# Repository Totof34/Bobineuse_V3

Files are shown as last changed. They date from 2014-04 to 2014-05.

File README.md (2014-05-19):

Bobineuse_V3
============

The project describes a stand-alone coil winder

If you would have more information about this project please visit 
www.audiyofan.org

A link to the dedicated post 
http://www.audiyofan.org/forum/viewtopic.php?f=73&t=7176&start=105

PCB & schema are designed with Kicad

the motor part uses a DC motor with a home made supply described below

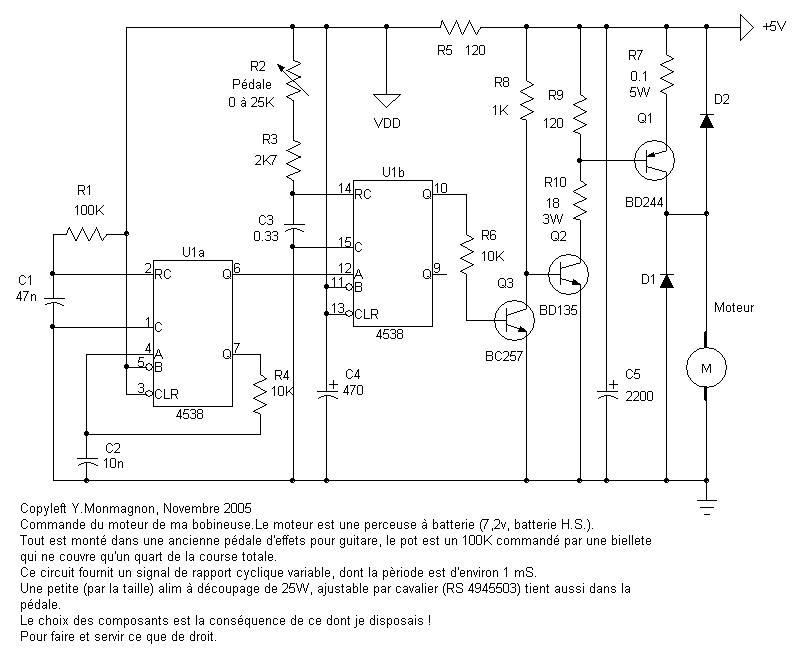
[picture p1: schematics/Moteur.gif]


The prototype of the display and the buttons

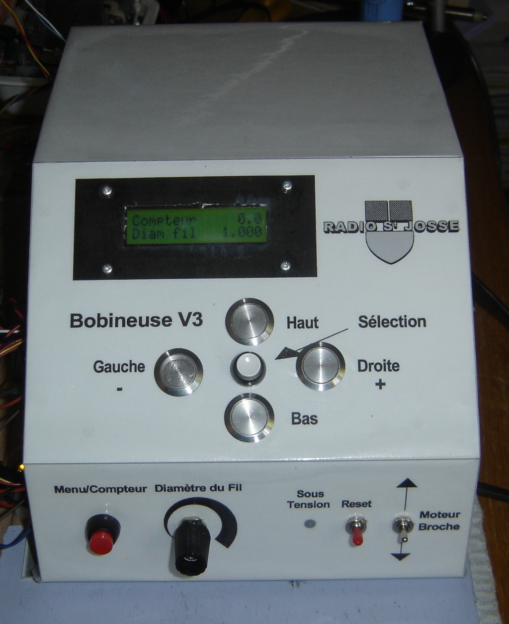
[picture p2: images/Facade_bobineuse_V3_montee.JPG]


The optical fork's disc 

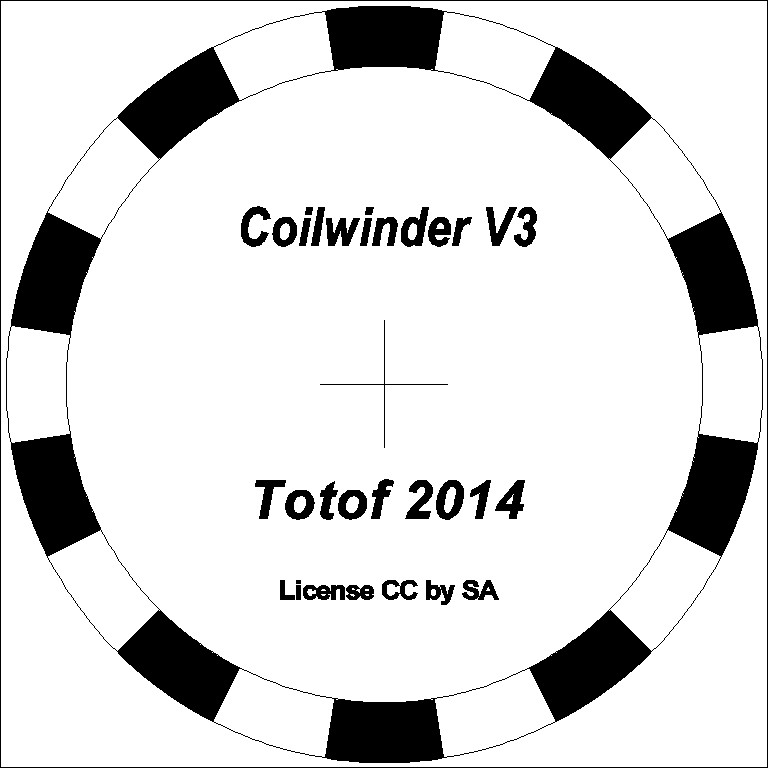
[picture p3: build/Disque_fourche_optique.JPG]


Everything that goes around the Leonardo's board

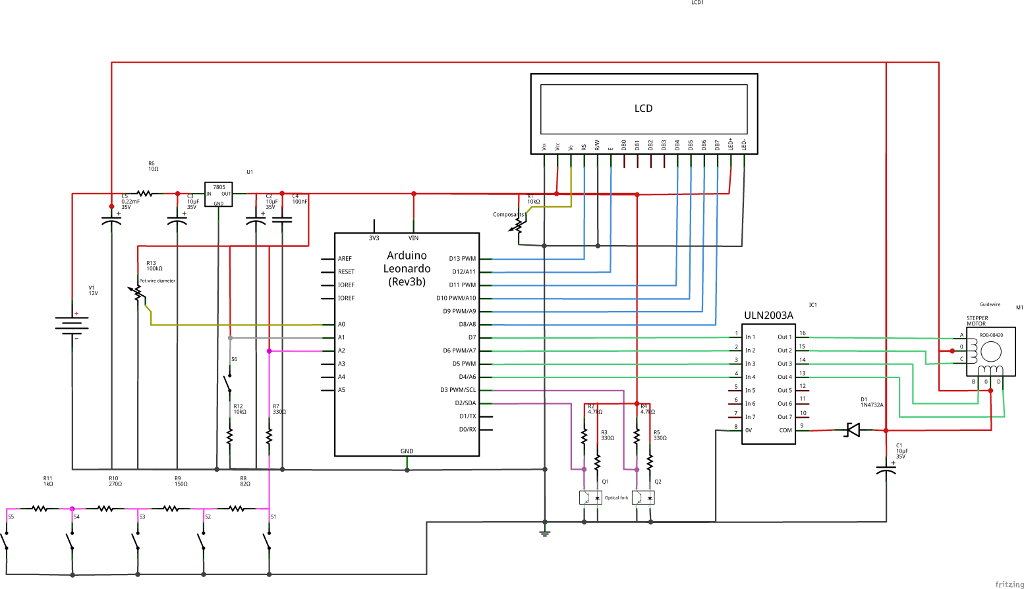
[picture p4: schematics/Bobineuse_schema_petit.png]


Here the function than my program include and which seems to me appropriate

 1° automatic counting and uncounting
 
 2° counting from zero or down from a specified number of turns
 
 3° initial point or initial carcass start recordable and reminder 
 
 4° guide wire enslaved on the up / down counting
 
 5° automatic reversing guide wire depending on the number of turns per layer and change side
 
 6° manual correction of errors in advance of the guide wire, losses step essentially
 
 7° Manual correction of counting errors
 
 8° management parameters by a "management" menu and a second separate part for the counting itself
 
 9° recordings of 10 different configurations to facilitate the winding of several transformers,
    by recording the primary and secondary sections separately and recall stored data in memory
    
10° display menus on 16x2 characters LCD

Of course my Leonardo's board also allows PC control if you wanted to, but I prefer a
standalone machine

See in the arduino folder for the sketch

Detail of the guidewire

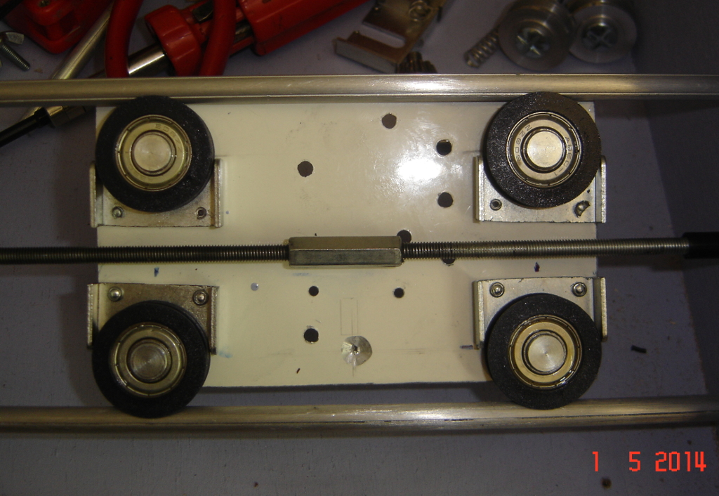
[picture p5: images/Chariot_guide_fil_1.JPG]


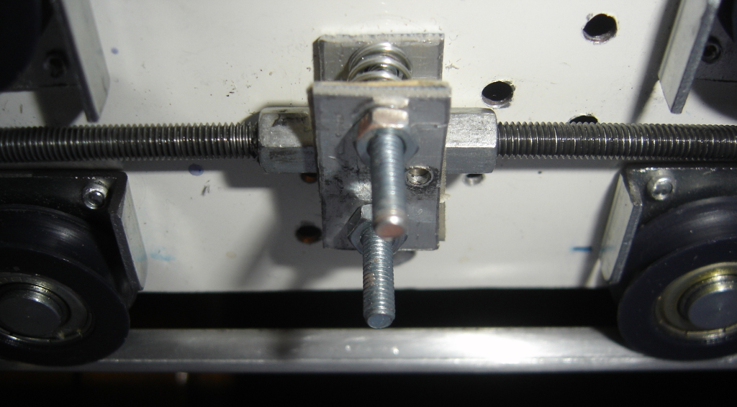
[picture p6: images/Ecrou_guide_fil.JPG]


Implementation of electronic boards in progress

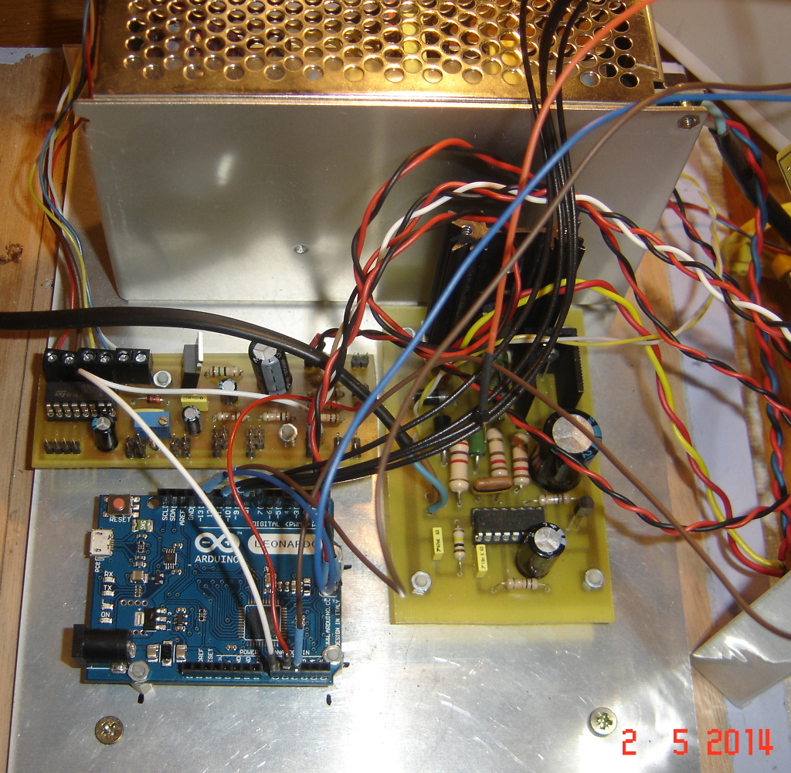
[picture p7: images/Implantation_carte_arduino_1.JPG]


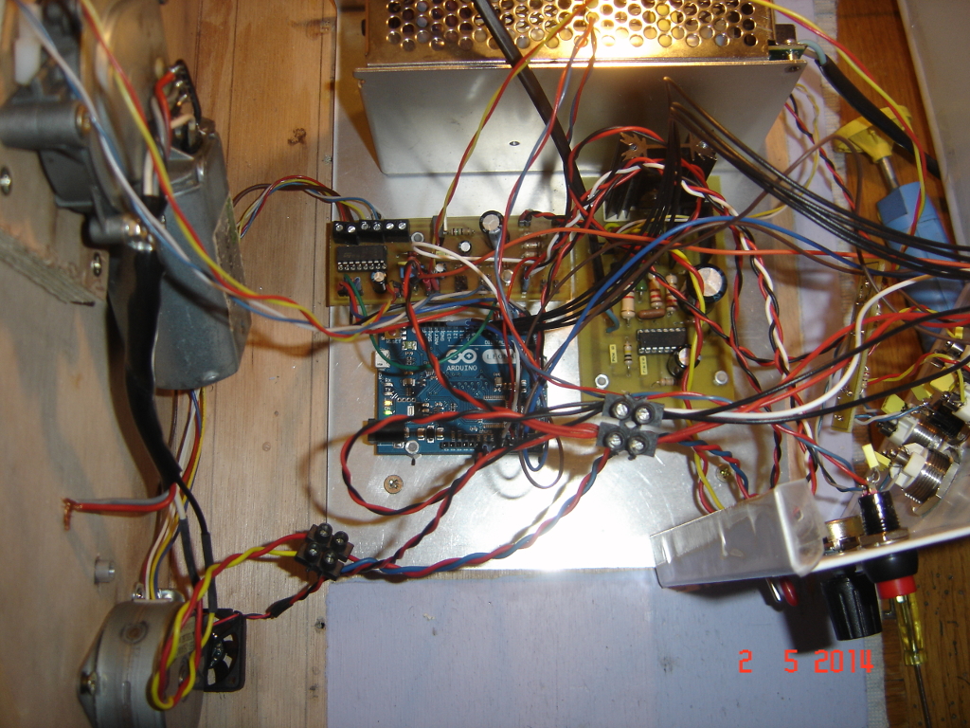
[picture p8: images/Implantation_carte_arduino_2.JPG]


Work in progress

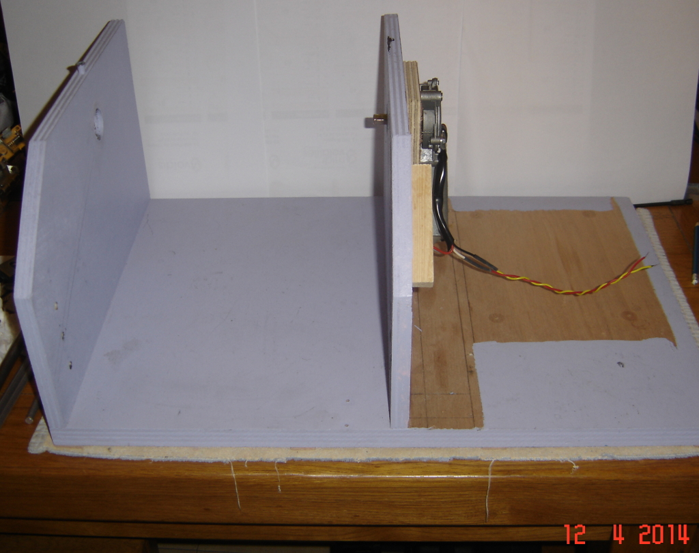
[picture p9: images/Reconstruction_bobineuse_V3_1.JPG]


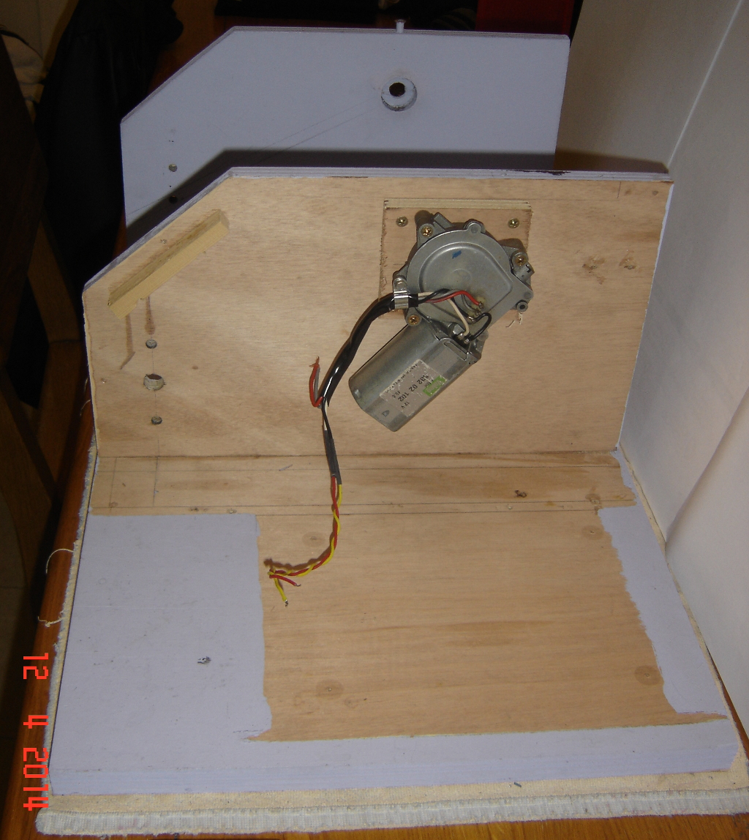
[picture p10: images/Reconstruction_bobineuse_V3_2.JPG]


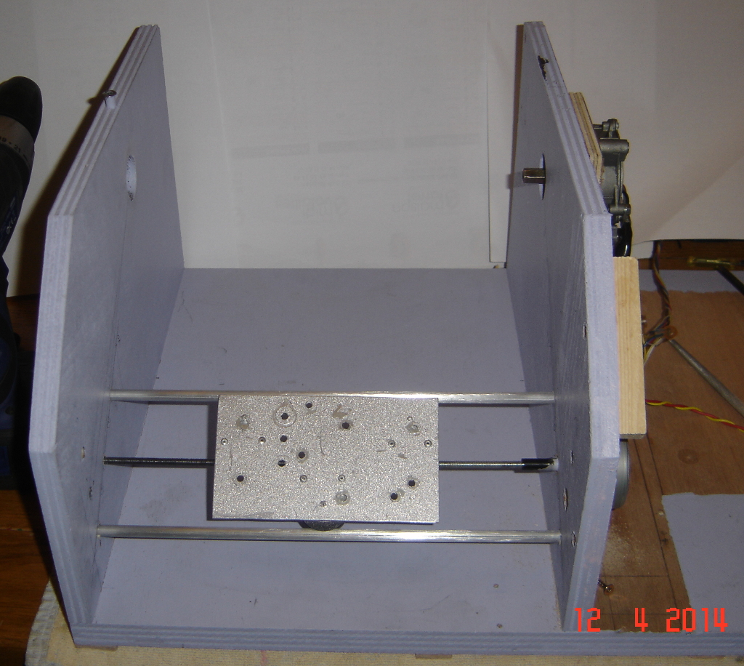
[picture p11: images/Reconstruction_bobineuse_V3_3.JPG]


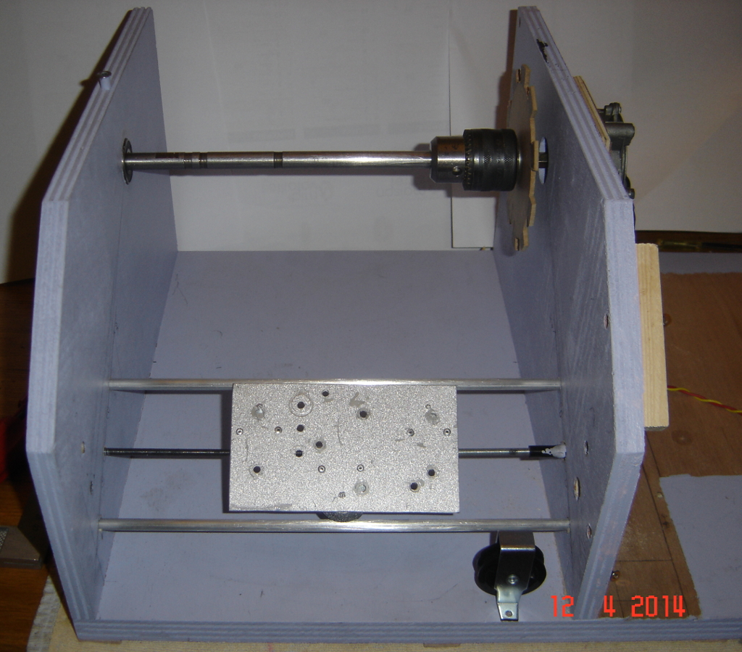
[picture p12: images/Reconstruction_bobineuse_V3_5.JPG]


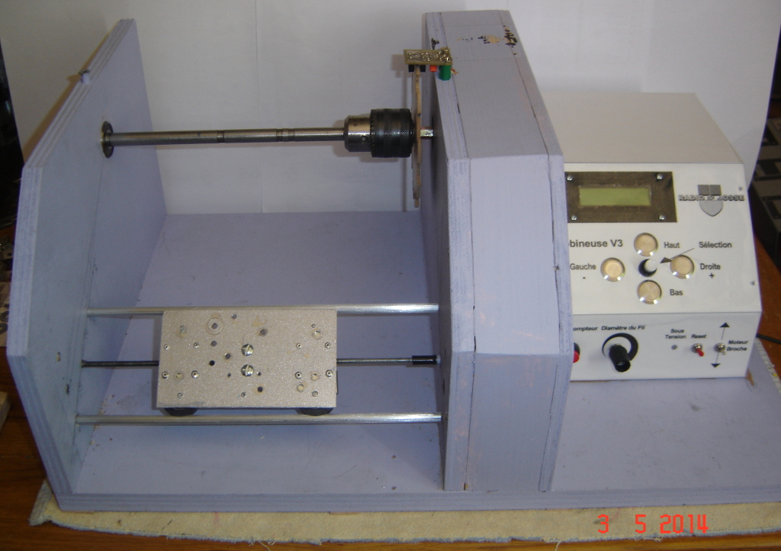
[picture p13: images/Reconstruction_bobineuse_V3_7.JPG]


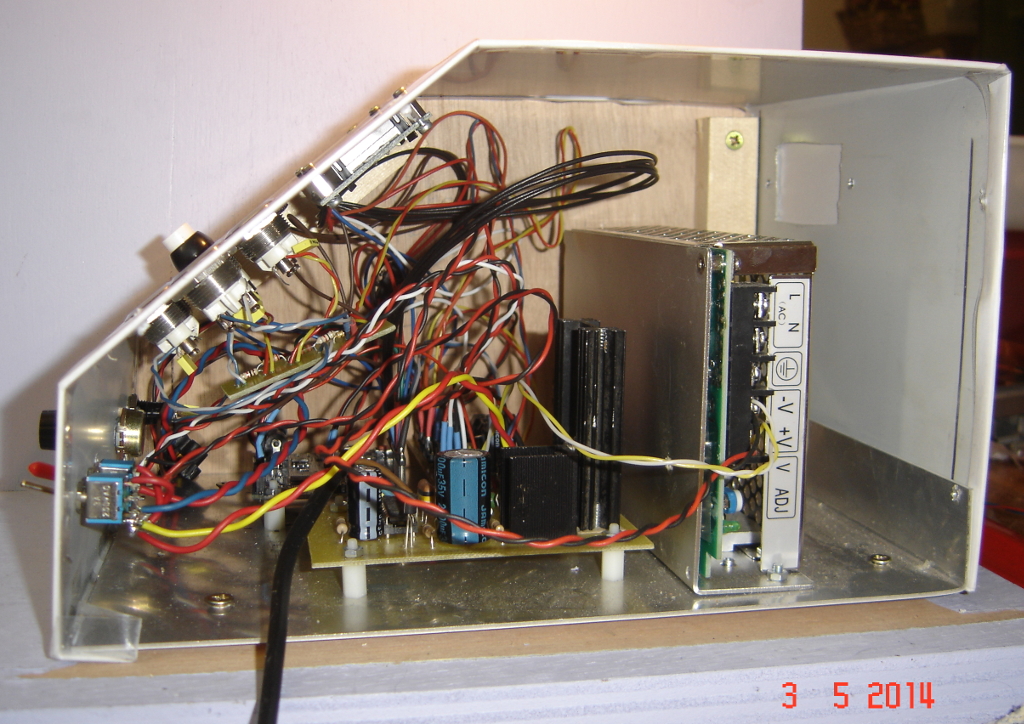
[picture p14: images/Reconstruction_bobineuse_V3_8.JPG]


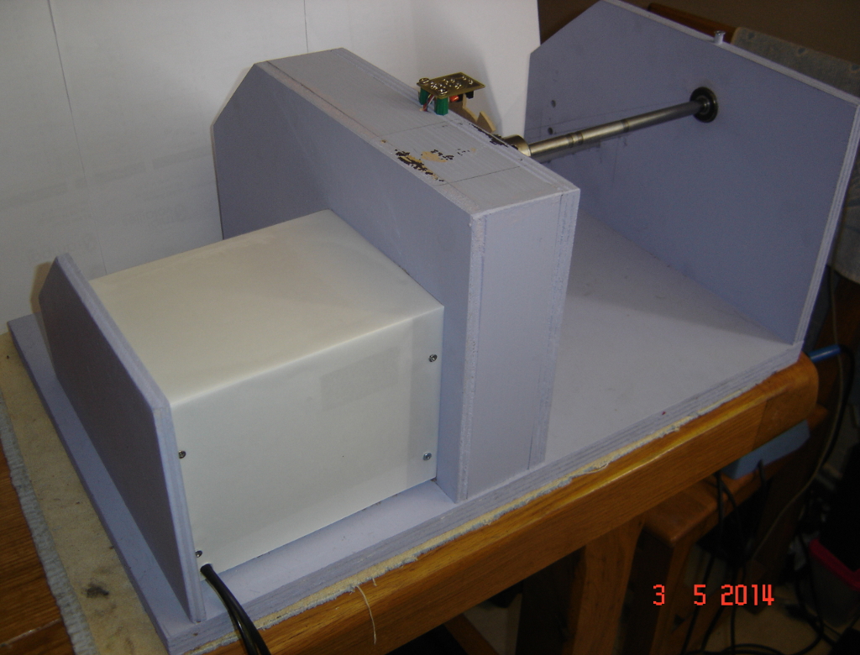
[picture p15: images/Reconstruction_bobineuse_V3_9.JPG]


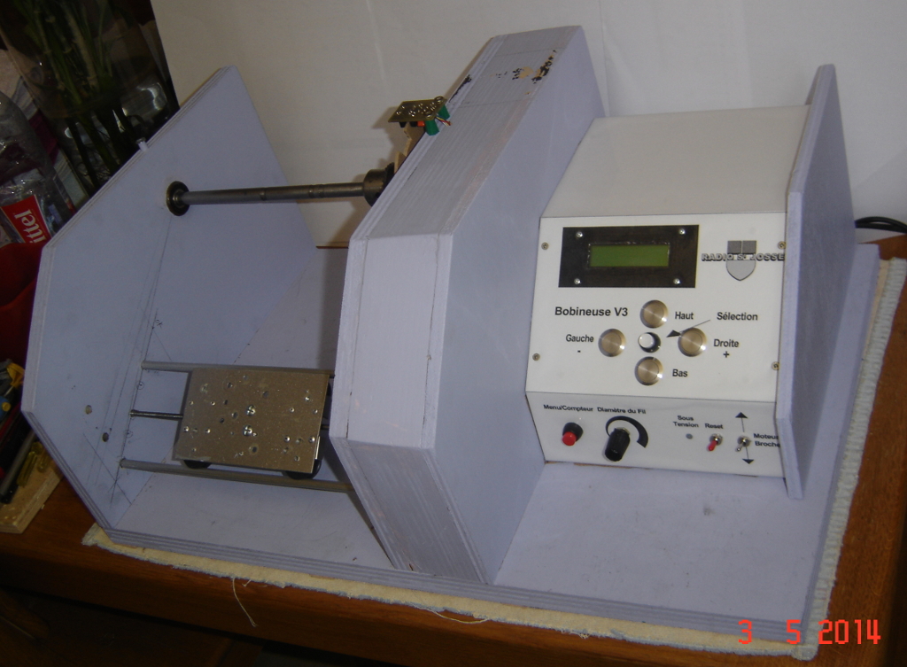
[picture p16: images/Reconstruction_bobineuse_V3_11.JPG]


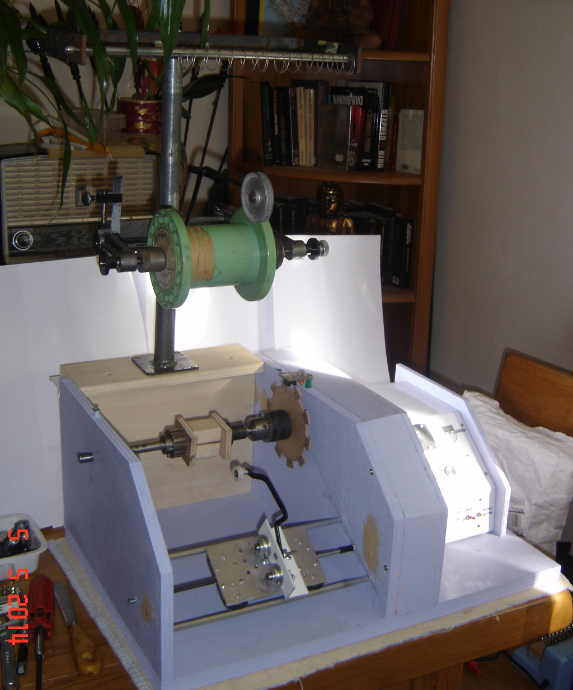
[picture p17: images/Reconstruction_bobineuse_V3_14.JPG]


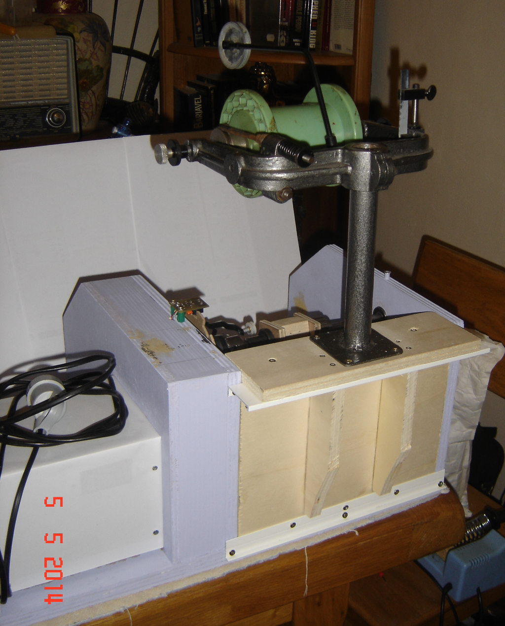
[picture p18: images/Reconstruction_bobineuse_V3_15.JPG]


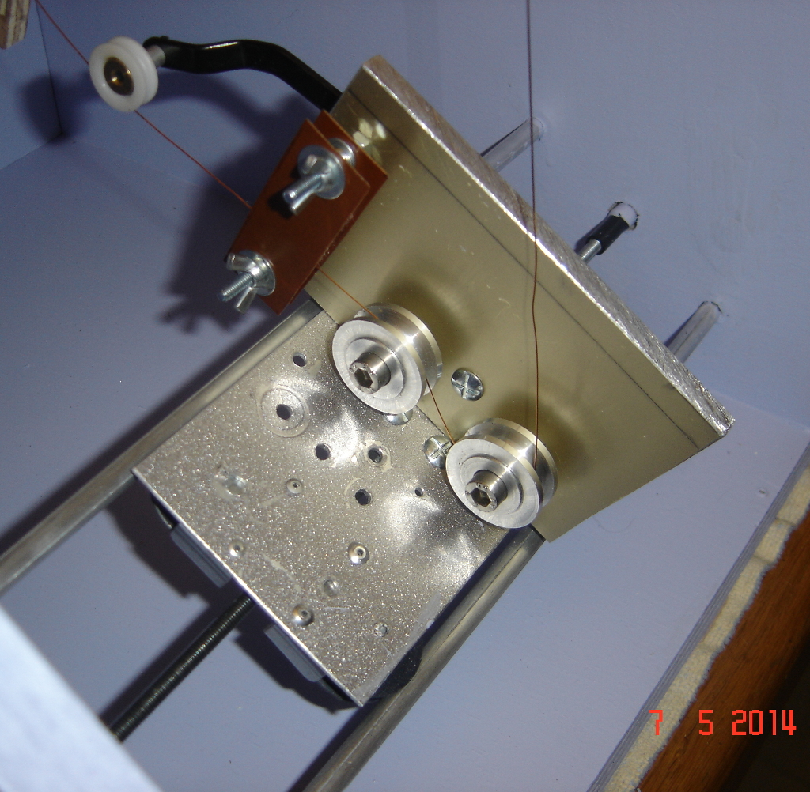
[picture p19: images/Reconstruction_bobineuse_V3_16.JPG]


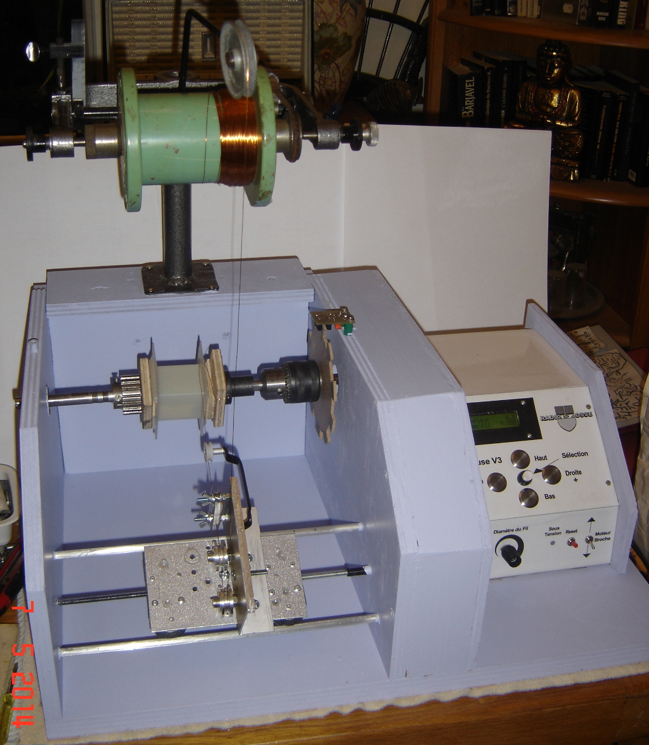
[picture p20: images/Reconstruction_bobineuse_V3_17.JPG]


The coilwinder in function 

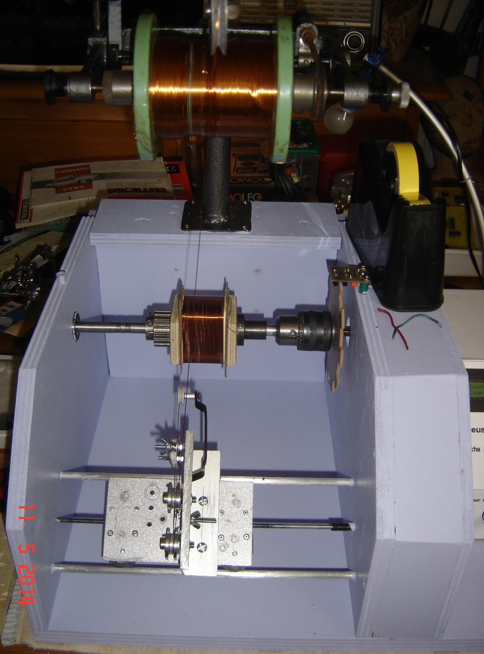
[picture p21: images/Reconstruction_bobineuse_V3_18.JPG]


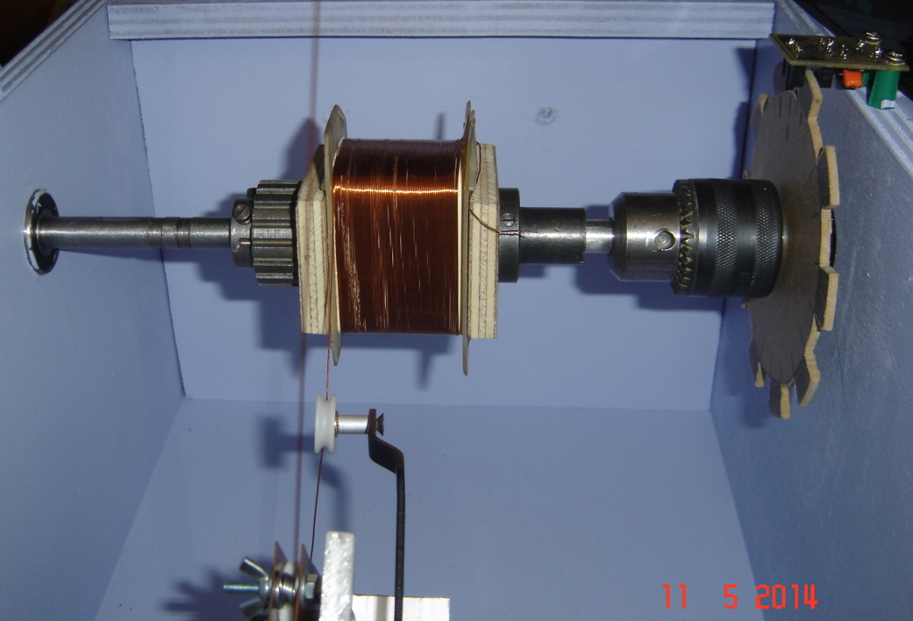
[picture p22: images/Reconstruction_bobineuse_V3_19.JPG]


Addition of a carrier for high copper coil

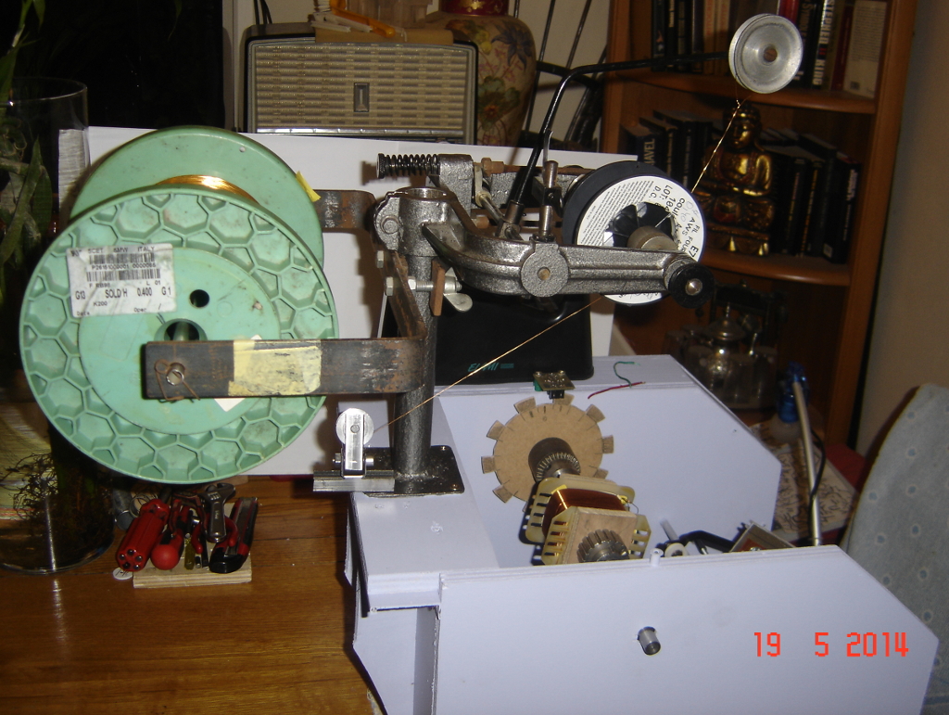
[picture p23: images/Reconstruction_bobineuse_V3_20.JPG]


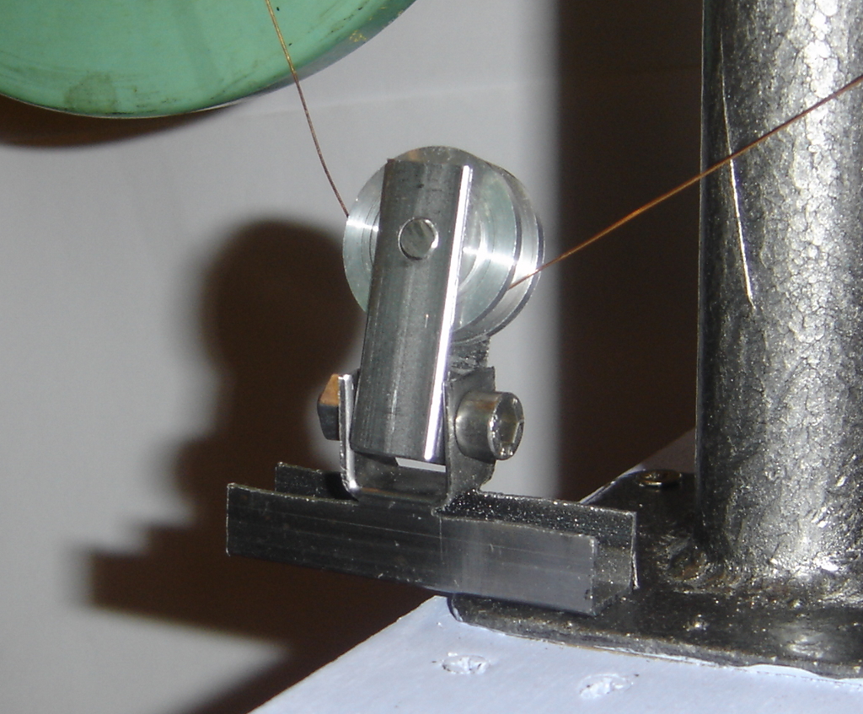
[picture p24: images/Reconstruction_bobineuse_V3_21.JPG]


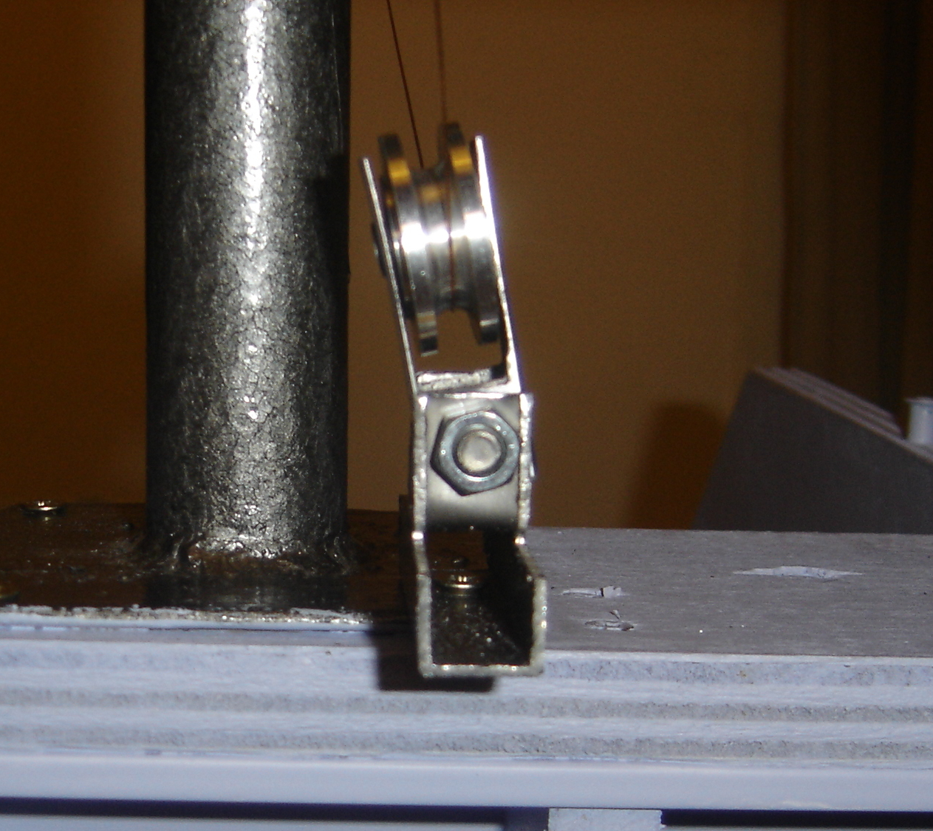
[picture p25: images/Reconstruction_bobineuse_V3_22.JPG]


All comments are welcome

Totof

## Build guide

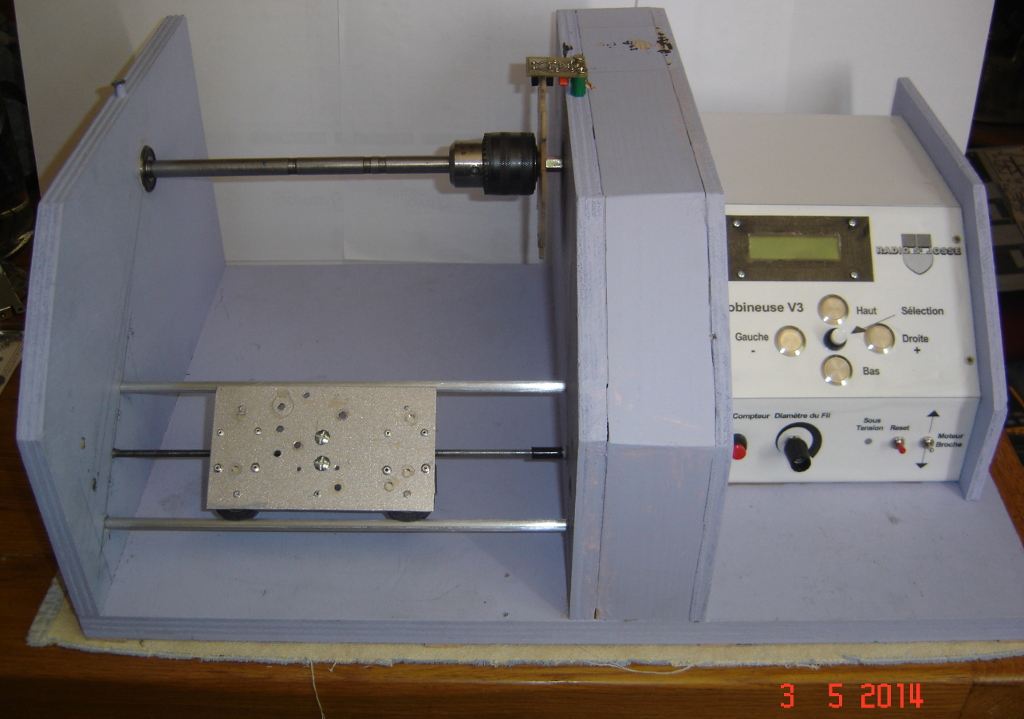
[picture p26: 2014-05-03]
images/Reconstruction_bobineuse_V3_10.JPG

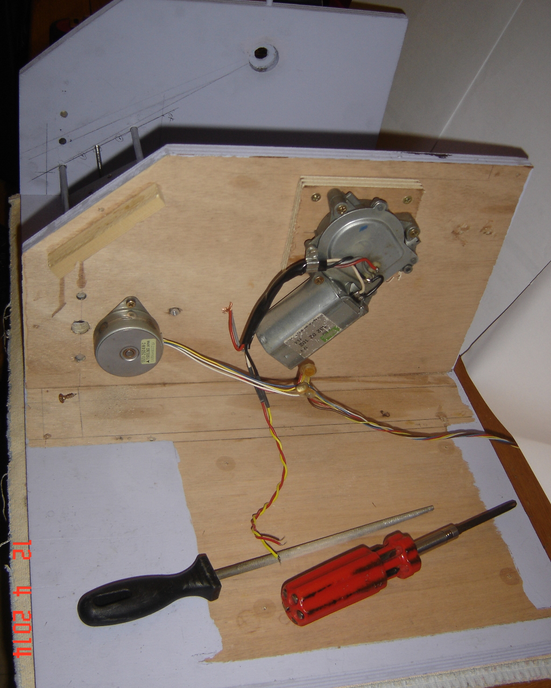
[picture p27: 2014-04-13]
images/Reconstruction_bobineuse_V3_4.JPG

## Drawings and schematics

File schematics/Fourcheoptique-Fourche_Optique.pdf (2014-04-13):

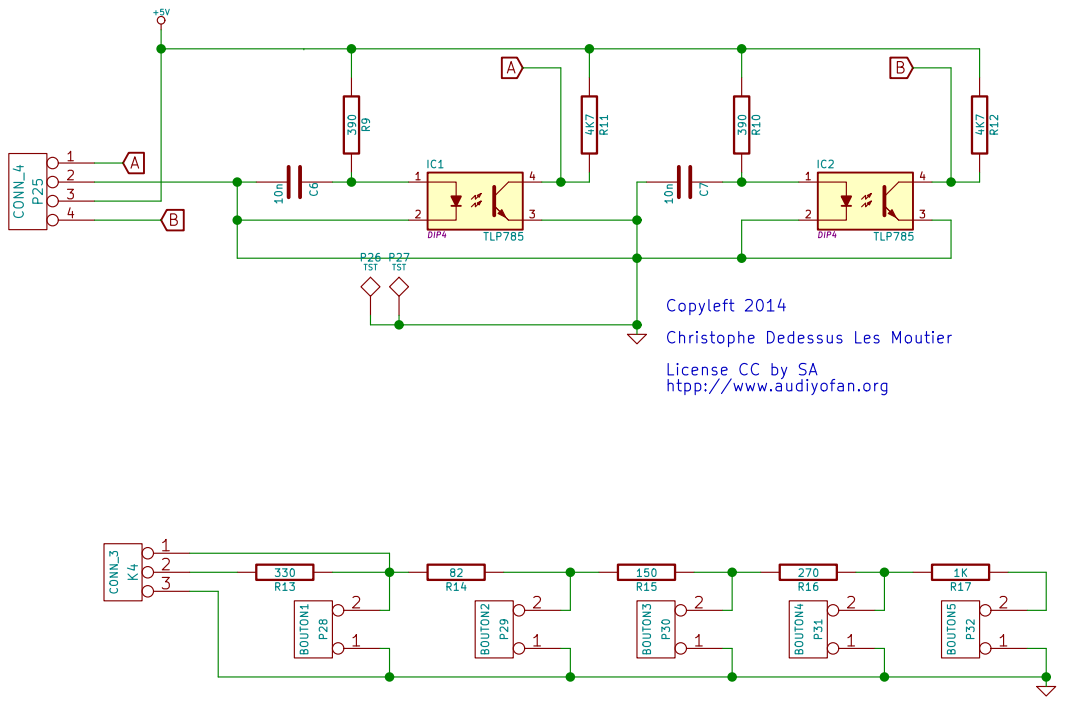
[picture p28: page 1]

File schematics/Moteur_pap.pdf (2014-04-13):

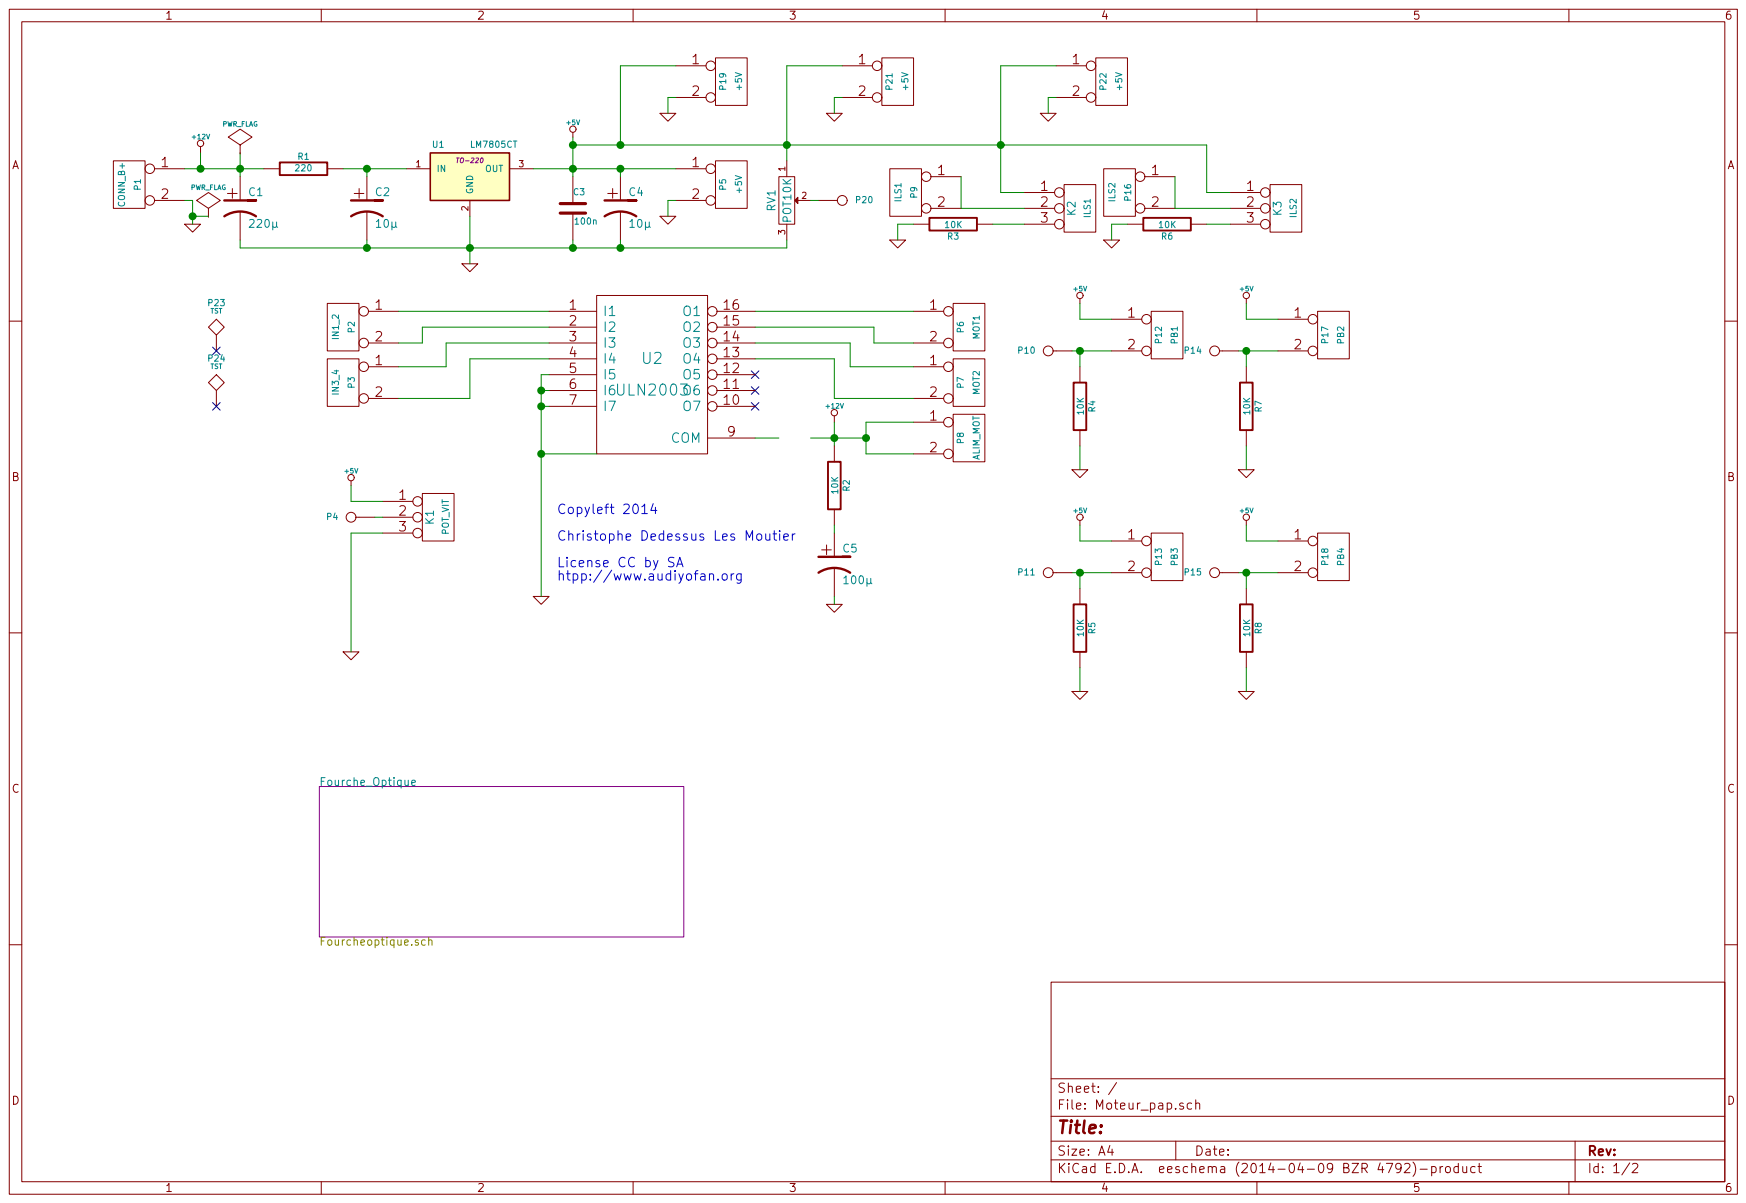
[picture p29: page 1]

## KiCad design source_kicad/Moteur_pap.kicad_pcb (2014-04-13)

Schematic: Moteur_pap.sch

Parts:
C1: 220µ
C2, C4: 10µ
C3: 100n
C5: 100µ
D1: ZENER24V
K1: POT_VIT
K2: ILS1
K3: ILS2
P1: CONN_B+
P2: IN1_2
P3: IN3_4
P4: WIPPER
P5, P19, P21, P22: +5V
P6: MOT1
P7: MOT2
P8: ALIM_MOT
P9: ILS1
P10, P12: PB1
P11, P13: PB3
P14, P17: PB2
P15, P18: PB4
P16: ILS2
P20: LVO
P23, P24: TST
R1: 220
R2, R3, R4, R5, R6, R7, R8: 10K
RV1: POT10K
U1: LM7805CT; TO-220
U2: ULN2003

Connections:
+5V: C3.1, C4.1, K1.1, K2.1, K3.1, P5.1, P12.1, P13.1, P17.1, P18.1, P19.1, P21.1, P22.1, RV1.1, U1.3 (OUT); also elsewhere on the board
+12V: C1.1, D1.1, P1.1, P8.1, P8.2 (PM), R1.1, R2.1
GND: C1.2, C2.2, C3.2, C4.2, C5.2, K1.3, P1.2 (PM), P5.2 (PM), P19.2 (PM), P21.2 (PM), P22.2 (PM), R3.2, R4.2, R5.2, R6.2, R7.2, R8.2, RV1.3, U1.2 (GND), U2.5 (I5), U2.6 (I6), U2.7 (I7), U2.8 (GND); also elsewhere on the board
unnamed: C2.1, R1.2, U1.1 (IN)
unnamed: C5.1, R2.2
unnamed: D1.2, U2.9 (COM)
unnamed: K1.2 (PM), P4.1
unnamed: K2.2 (PM), P9.1, P9.2 (PM)
unnamed: K2.3, R3.1
unnamed: K3.2 (PM), P16.1, P16.2 (PM)
unnamed: K3.3, R6.1
unnamed: P2.1, U2.1 (I1)
unnamed: P2.2 (PM), U2.2 (I2)
unnamed: P3.1, U2.3 (I3)
unnamed: P3.2 (PM), U2.4 (I4)
unnamed: P6.1, U2.16 (O1)
unnamed: P6.2 (PM), U2.15 (O2)
unnamed: P7.1, U2.14 (O3)
unnamed: P7.2 (PM), U2.13 (O4)
unnamed: P10.1, P12.2 (PM), R4.1
unnamed: P11.1, P13.2 (PM), R5.1
unnamed: P14.1, P17.2 (PM), R7.1
unnamed: P15.1, P18.2 (PM), R8.1
unnamed: P20.1, RV1.2

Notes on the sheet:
Copyleft 2014 Christophe Dedessus Les Moutier License CC by SA htpp://www.audiyofan.org

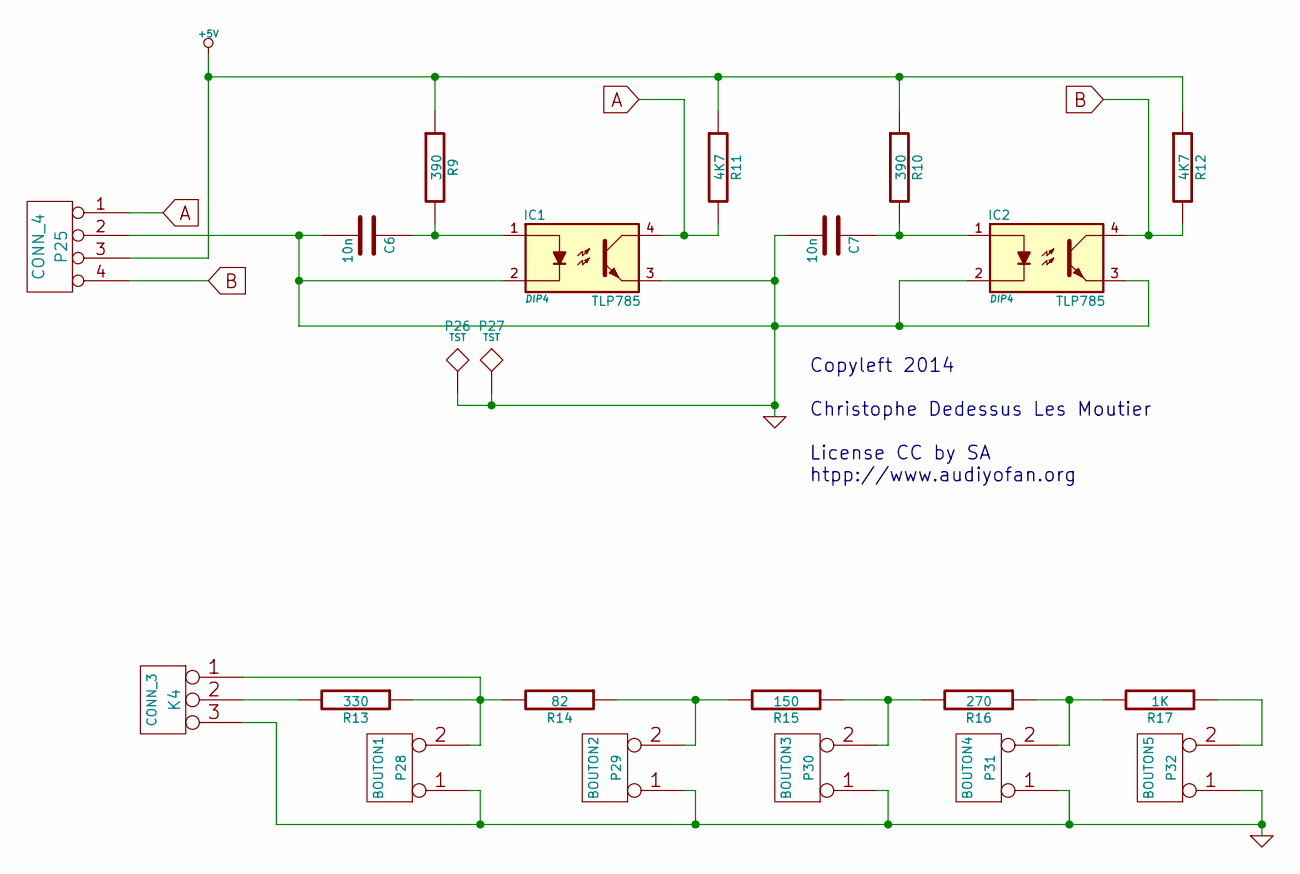
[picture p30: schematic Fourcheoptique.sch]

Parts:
C6, C7: 10n
IC1, IC2: TLP785; DIP4
K4: CONN_3
P25: CONN_4
P26, P27: TST
P28: BOUTON1
P29: BOUTON2
P30: BOUTON3
P31: BOUTON4
P32: BOUTON5
R9, R10: 390
R11, R12: 4K7
R13: 330
R14: 82
R15: 150
R16: 270
R17: 1K

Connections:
+5V: P25.3, R9.1, R10.1, R11.1, R12.1; also elsewhere on the board
A: IC1.4, P25.1, R11.2
B: IC2.4, P25.4, R12.2
GND: C6.2, C7.2, IC1.2, IC1.3, IC2.2, IC2.3, K4.3, P25.2, P26.1, P27.1, P28.1, P29.1, P30.1, P31.1, P32.1; also elsewhere on the board
unnamed: C6.1, IC1.1, R9.2
unnamed: C7.1, IC2.1, R10.2
unnamed: K4.1, P28.2 (PM), R13.1, R14.2
unnamed: K4.2 (PM), R13.2
unnamed: P29.2 (PM), R14.1, R15.2
unnamed: P30.2 (PM), R15.1, R16.2
unnamed: P31.2 (PM), R16.1, R17.2
unnamed: P32.2 (PM), R17.1

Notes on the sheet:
Copyleft 2014 Christophe Dedessus Les Moutier License CC by SA htpp://www.audiyofan.org

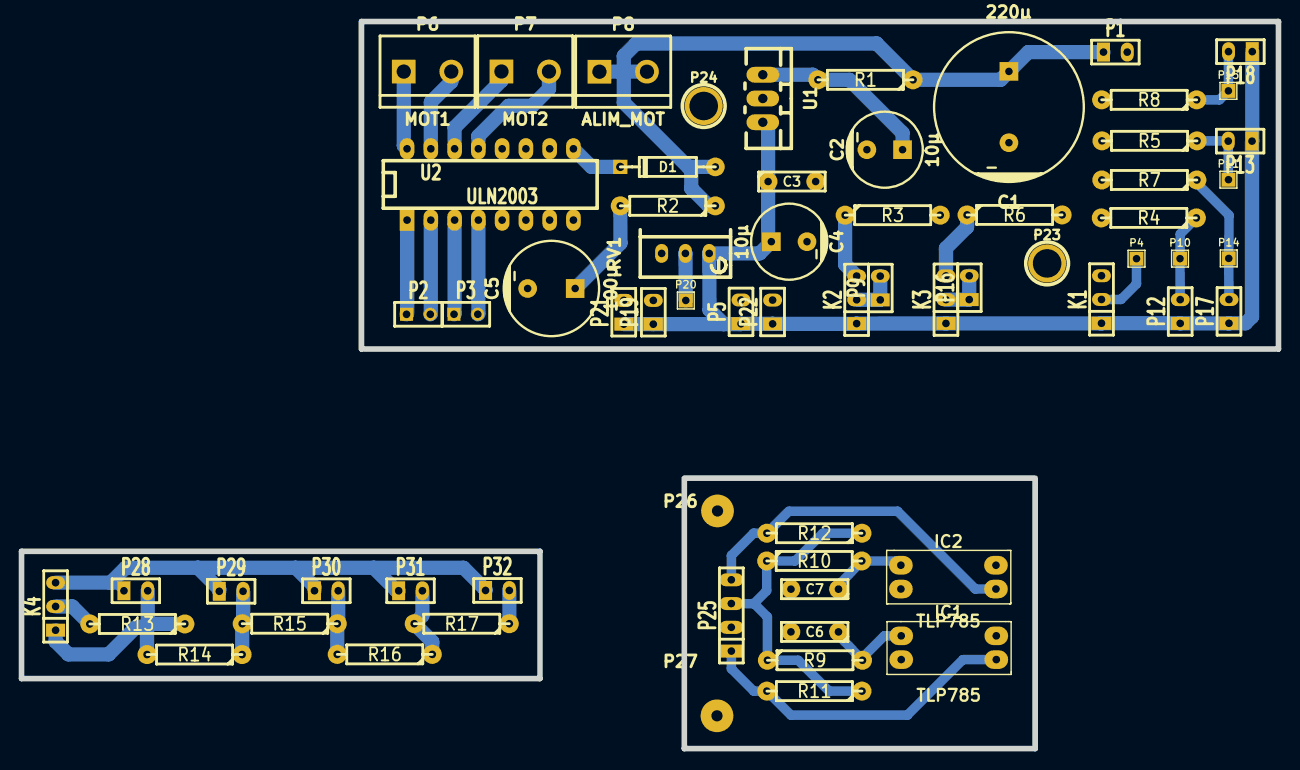
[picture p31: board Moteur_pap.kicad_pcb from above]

Board: 2 copper layers, 134.3 x 77.7 mm, 66 parts (0 on the bottom side), 34 nets.

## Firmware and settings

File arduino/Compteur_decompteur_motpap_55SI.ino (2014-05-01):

/*
  LiquidCrystal Library - 
  
  Le circuit:
 * FORK A to digital pin 2
 * FORK B to digital pin 1
 * LCD RS pin to digital pin 12
 * LCD Enable pin to digital pin 11
 * LCD D4 pin to digital pin 10
 * LCD D5 pin to digital pin 9
 * LCD D6 pin to digital pin 8
 * LCD D7 pin to digital pin 7
 * LCD R/W pin to ground
 * 10K resistor:
 * ends to +5V and ground
 * wiper to LCD VO pin (pin 3)
 
 Library originally added 18 Apr 2008
 by David A. Mellis
 library modified 5 Jul 2009
 by Limor Fried (http://www.ladyada.net)
 example added 9 Jul 2009
 by Tom Igoe
 modified 22 Nov 2010
 by Tom Igoe
 
 This example code is in the public domain.

 http://www.arduino.cc/en/Tutorial/LiquidCrystal
 */
/*******************************************************

 Gestion de menu – v1
 Par Yersinia Programs

 http://yersiniaprograms.wordpress.com/
 

********************************************************/

/*******************************************************
Bobineuse V3

Ce programme gère l'affichage de la bobineuse et la gestion moteur
 Affiche sur l'écran LCD le nombre de spires et le nombre de spires par couche
 Gère l'avance du moteur pàp en fonction du diamètre du fil
 stocke le nombre de spire et le nombre de spire par couche 
 permet de rappeler les données enregistrées dans 10 zones de stockage de l'EEPROM
 
 CC by SA 
 Totof 2014
 
 Pour toute info complémentaire un lien ici
 http://www.audiyofan.org/forum/viewtopic.php?f=73&t=7176&start=105
 
 www.audiyofan.org
 
 ********************************************************/

// include the library code:
#include <LiquidCrystal.h>
#include <Stepper.h>
#include <EEPROM.h>

// Définition des PIN
#define Fourche_A  2     
#define Fourche_B  1 

// Définition des variables
// Mémorise l'état des sorties A et B
int StateA = 0; 
int StateB = 0;
// Mémorise l'état des sorties A et B antérieures
int StateA_anterieur = 0; 
int StateB_anterieur = 0; 

int Compteur = 0;
int Compteur_anterieur = 0;
int Compteur_impulsion = 0;
int Compteurspcouche = 0;
int Sensspirecouche = 0;
int Sensdebutcouche = 1;
int Senschangecote = 1;
int Avancechangecote = 0;
int Position = 0;

int lcd_keyA1     = 0;
boolean choixmenu = 0;

float Nbspire = 0;
float Pasvis = 0.80;// Défini le pas de la tige filetée actuellement 5mm de diamètre
int Sense = 0;// Défini le sens de rotation de l'arbre principal
int Steps = 0;// Déini le nombre de pas pour le mot pàp de l'avance quide fil

int val = 0;
int stepsMaped = 0;// Transforme la lecture analogique du potentiomètre 
// Mémorise le diamètre du fil
float fFil = 0;

// Modification des settings Arduino d'origine pour améliorer la conversion
// analogique vers numérique et ainsi augmenter la vitesse de traitement
// avec ces réglages une conversion prend 24 µs
// Define various ADC prescaler
const unsigned char PS_16 = (1 << ADPS2);
const unsigned char PS_128 = (1 << ADPS2) | (1 << ADPS1) | (1 << ADPS0);

// define some values used by the panel and buttons
int lcd_key     = 0;
int adc_key_in  = 0;
int cumul_spire = 0;
int cumul =0;
float reste_compteur = 0;
int retour_compteur = 0;
int cumul_couche = 0;

int A = 0;
int B = 0;
int C = 0;
int D = 0;
int E = 0;
int F = 0;
int G = 0;
int H = 0;
int I = 0;
int J = 0;
int K = 0;
int L = 0;
int M = 0;
int X = 0;
int Y = 0;
int Z = 0;

boolean choix = 0;
int up;
int ancien_boutton;
int ancien_boutton_menu;
int droit;
int select;
int valeur;
int numerosauvegarde;


// initialize the library with the numbers of the interface pins
LiquidCrystal lcd(12, 11, 10, 9, 8, 7);

// initialize the stepper library on pins 8 through 11:
// 48 is the number of steps per revolution,change this to fit the number of steps per revolution
// Réglage pour le moteur 55SI-25DAWC
// Brochage des fils en sortie de l'ULN2003 
// Pin 16 Rouge 55SI-25DAWC, Rose   ST35,
// Pin 15 Brun  55SI-25DAWC, Orange ST35,
// Pin 14 Jaune 55SI-25DAWC, Jaune  ST35,
// Pin 13 Bleu  55SI-25DAWC, Bleu   ST35,
Stepper myStepper(48,6,5,4,3);

// initialisation du menu
char menu_text [7][8][17] = {
{
{"Nb de spires  =>"}, {"Millier       =>"}, {"Centaine      =>"}, {"Dizaine       =>"}, {"Unite         =>"}, {"Dizieme         "},             {"null"}, {"null"}
},   
{
{"Cumul compt   =>"}, {"Comptage      =>"}, {"Decomptage      "},             {"null"},             {"null"},             {"null"},             {"null"}, {"null"}
},
{
{"Spire/couche  =>"}, {"Centaine      =>"}, {"Dizaine       =>"}, {"Unite         =>"}, {"Debut Gauche  =>"}, {"Debut Droite    "},             {"null"}, {"null"}
},
{
{"Guide fil     =>"}, {"- 1/2 tour    =>"}, {"+ 1/2 tour    =>"}, {"- 1/8 tour    =>"}, {"+ 1/8 tour    =>"}, {"Change de cote  "},             {"null"}, {"null"}
},
{
{"Position init =>"}, {"Enregistrer   =>"}, {"Retour a 0    =>"}, {"- 10 tours    =>"}, {"+10 tours     =>"}, {"- 1 tour      =>"}, {"+ 1 tour      =>"}, {"null"}
},
{
{"Compteur      =>"}, {"+ 1/10        =>"}, {"- 1/10          "},             {"null"},             {"null"},             {"null"},             {"null"}, {"null"}
},      
{
{"Sauvegarde    =>"}, {"Choix numero  =>"}, {"Sauver        =>"}, {"Recharger       "},             {"null"},             {"null"},             {"null"}, {"null"}
}   
};

// Il faut mettre les enregistrements des valeurs dans un tableau à la place des 0
// Faire une fonction de parcours de tableau et de chargement des valeurs
// Puis faire un enregistrement directement dans le tableau qui donnera
// l’adresse de la case mémoire utilisé comme moyen de réutilisation
int menu_valeur [7][8][3] = {
{
{-21},  {0}, {0}, {0},  {0},  {0},  {-1},{-1}
},  
{
{-1}, {-2}, {-3}, {-1}, {-1}, {-1}, {-1},{-1}
},
{
{-22}, {0},  {0},  {0}, {-4}, {-5}, {-1},{-1}
},
{
{-1}, {-6}, {-7}, {-8}, {-9}, {-10},{-1},{-1}
},
{
{-1},{-11},{-12},{-13},{-14},{-15},{-16},{-1}
},
{
{-1}, {-17}, {-18}, {-1},{-1},{-1}, {-1},{-1}
},
{
{-1}, {0},{-19}, {-20}, {-1}, {-1}, {-1},{-1}
}
};
  
#define btnRIGHT  0
#define btnUP     1
#define btnDOWN   2
#define btnLEFT   3
#define btnSELECT 4
#define btnNONE   5

int menu_config [98];

void setup() {
  // set up the LCD's number of columns and rows: 
  lcd.begin(16, 2);
  // Print a message to the LCD.
  // lcd.print("Compteur");
  // Initialise les entrées A et B de l'encodeur
  pinMode(Fourche_A, INPUT); 
  pinMode(Fourche_B, INPUT);
  // set up the ADC
  ADCSRA &= ~PS_128;  // remove bits set by Arduino library
  // you can choose a prescaler from above.
  // PS_16, PS_32, PS_64 or PS_128
  ADCSRA |= PS_16;    
  // set our own prescaler to 16 
  // set the speed at 300 rpm:
  myStepper.setSpeed(300);
    
}

void loop() {
  
  Selection();
  
  if (choixmenu == 0)
    {
     
    Comptage();
    
    Compteimpulsion();
    
    AfficheCompteur();
    
    Retournerestecompteur ();
    
    Diamfil();
    
    AfficheDiamFil();
    
    Nombrespirecouche();
    
    Gestionstep();
        
    Avanceguidefil();
    
    Positioncourante();
           
    }
    
  if (choixmenu == 1)
    {
    
    Gestionboutons ();
    
    Gestionvaleur ();
    
    Affichagemenutext();
   
    delay(20);
    
    }
   
   
}

/*******************************************************
*******************************************************/

// Fonction de comptage
void Comptage()
{
    // Lecture des sorties A et B de l'encodeur. Avant chaque lecture,
  // mémorisation de l'état antérieur de chaque broche. Ce principe permet
  // la détection d'un front montant.
  StateA_anterieur= StateA;
  StateA = digitalRead(Fourche_A);
  StateB_anterieur= StateB;  
  StateB = digitalRead(Fourche_B);

  // Détection du front montant :
  // Etat actuel : haut, état antérieur : bas
  if ((StateA == HIGH) && (StateA_anterieur == LOW)) { 
    if (StateB == LOW) {
      Sense = 1;      
      }
    
    };  

  // Détection du front montant :
  // Etat actuel : haut, état antérieur : bas
  if ((StateB == HIGH) && (StateB_anterieur == LOW)) { 
    if (StateA == LOW) {
      Sense = -1;      
      };    
    }
}

/*******************************************************
*******************************************************/

// Fonction comptage des impulsions
void Compteimpulsion()
{
  A = abs(Compteur_impulsion);
  
  if (A<10)
  {
   Compteur_impulsion = Compteur_impulsion + Sense;
  }
  else 
  {
   Compteur_impulsion = 0;
  } 

}

/*******************************************************
*******************************************************/

// Fonction d'affichage du compteur
void AfficheCompteur()
{
  if (menu_config [0] == 0)
  {
  Compteur = Compteur + Sense;
  Nbspire=Compteur*0.1;
  // set the cursor to column 12, line 0
  // (note: line 1 is the second row, since counting begins with 0):
  lcd.setCursor(0,0);
  lcd.print("Compteur   ");
  lcd.setCursor(9,0);
  // reset the screen:
  lcd.print("       ");
  // set the cursor to column 12, line 0
  Affichenombre(); 
  }
  else if (menu_config [0] == 1)
  {
  cumul_spire = cumul_spire - Sense;
  Nbspire=cumul_spire*0.1;
  // set the cursor to column 12, line 0
  // (note: line 1 is the second row, since counting begins with 0):
  lcd.setCursor(0,0);
  lcd.print("Reste     ");
  lcd.setCursor(9,0);
  // reset the screen:
  lcd.print("       ");
  // set the cursor to column 12, line 0
  Affichenombre(); 
  }
}

/*******************************************************
*******************************************************/

// Fonction de paramétrage de l'affichage du nombre de spires
void Affichenombre()
{
  if ((Nbspire <= -10) && (Nbspire > -100))
  {
   lcd.setCursor(11,0);
   lcd.print(Nbspire,1); 
  }
  if ((Nbspire < 0) && (Nbspire > -10))
  {
   lcd.setCursor(12,0);
   lcd.print(Nbspire,1); 
  }
  if (Nbspire >= 0)
  {
   lcd.setCursor(13,0);
   lcd.print(Nbspire,1); 
  }
  if (Nbspire >= 10)
  {
   lcd.setCursor(12,0);
   lcd.print(Nbspire,1); 
  }
  if (Nbspire >= 100)
  {
   lcd.setCursor(11,0);
   lcd.print(Nbspire,1);
   //delay(5); 
  }
  if (Nbspire >= 1000)
  {
   lcd.setCursor(10,0);
   lcd.print(Nbspire,1);
   delay(5); 
  }
}

/*******************************************************
*******************************************************/

// Fonction de paramétrage du diamètre du fil
void Diamfil()
{
  val=analogRead(A0);
  stepsMaped=map(val, 0, 1023, 0, 1008);
      
  // Doit etre calculé par rapport à la tige filetée 
  // 1 tour de tige filetée en pas de 1 revient à une avance de 1 mm
  // Soit 1/48 (par rapport au moteur)steps fois le nombre de steps d'avance
  // pour faire 1 tour complet du motoréducteur 
  // ici le codeur comporte 10 pulses par tour donc 0.02803333 * 0.1
  fFil = stepsMaped*Pasvis*0.002083333;
}

/*******************************************************
*******************************************************/

// Fonction d'affichage du diamètre du fil
void AfficheDiamFil()
{
  // set the cursor to column 0, line 1
  // (note: line 1 is the second row, since counting begins with 0):
  lcd.setCursor(0,1);
  // print the number of seconds since reset:
  lcd.print("Diam fil");
  // set the cursor to column 0, line 1
  // (note: line 1 is the second row, since counting begins with 0):
  lcd.setCursor(11,1);
  lcd.print(fFil,3); 
}

/*******************************************************
*******************************************************/

// Fonction D'avance du guide fil 
void Avanceguidefil()
{
  // revolution  in one direction or the other:
  Steps = (Sense*Sensspirecouche*Sensdebutcouche*B);
  myStepper.step(Steps);
  Sense = 0;
  B = 0;
  C = 0;
  D = 0;
}

/*******************************************************
*******************************************************/

// Fonction de gestion de la découpe du nombre de steps pour 
// remplir une révolution de la broche principale au step près
void Gestionstep()
{
 if ( A <= 7 )
    {
      B = int(stepsMaped*0.01);
    }
    else if ( A == 8 )
    {
      C = int((stepsMaped*0.1)-(int(stepsMaped*0.01)*8));
      B = int(C*0.5);
    }
    else if ( A == 9 )
    {
      C = int(int((stepsMaped*0.1)-(int(stepsMaped*0.01)*8))*0.5);
      D = (int(stepsMaped*0.01))*8;
      B = ((int(stepsMaped*0.1))-D)-C;            
    } 
}

/*******************************************************
*******************************************************/

// Fonction qui enregistre la position du guide fil 
void Positioncourante()
{
  Position = Position + Steps;
}

/*******************************************************
*******************************************************/
// Fonction pour entrer ou sortir du menu
int Selection()
{
  lcd_keyA1 = digitalRead(A1);
  if (ancien_boutton_menu != lcd_keyA1) // permet d’in/décrémenter que de 1 lors de l’appuie d’un bouton
  {
  if (lcd_keyA1 == HIGH)
  {
    choixmenu = !choixmenu;
  }
  ancien_boutton_menu = lcd_keyA1;
  }
}

/*******************************************************
*******************************************************/

// Partie qui gère l'affichage du menu


// Fonction qui gère la lecture des boutons et qui retourne 
// le bouton appuyés
int Lecture_LCD_bouttons()
{
adc_key_in = analogRead(A2);      // read the value from the sensor
// my buttons when read are centered at these valies: 0, 144, 329, 504, 741
// we add approx 50 to those values and check to see if we are close
if (adc_key_in > 1000) return btnNONE; // We make this the 1st option for speed reasons since it will be the most likely result
//lcd.setCursor(0,0);
//lcd.print(adc_key_in);
// For V1.0 us this threshold
if (adc_key_in < 50)   return btnRIGHT;
if (adc_key_in > 150 && adc_key_in < 250)  return btnUP;
if (adc_key_in > 375 && adc_key_in < 475)  return btnDOWN;
if (adc_key_in > 565 && adc_key_in < 665)  return btnLEFT;
if (adc_key_in > 795 && adc_key_in < 895)  return btnSELECT;

}

/*******************************************************
*******************************************************/

// Fonction gestion des retours boutons
void Gestionboutons ()
{
 lcd_key = Lecture_LCD_bouttons();
 if (ancien_boutton != lcd_key) // permet d’in/décrémenter que de 1 lors de l’appuie d’un bouton
 {
 switch (lcd_key)
 {
 case btnRIGHT:
 {
 if (choix == 0)
 {
 if (droit < 7)
 {
 droit++;
 }
 else 
 {
 droit=0; 
 }
 }
 
 if (choix == 1)
 {
 if (valeur <= 8)
 {
   valeur++;
 }
 else
 {
   valeur = 0;
 }  
 }
 }
 
 break;
 

 case btnLEFT:
 {
 if (choix == 0)
 {
 if (droit > 0) 
 {
 droit--;
 }
 else
 { }
 }
 if (choix == 1)
 {
 if (valeur >= 1)
 {
   valeur--;
 }
 else
 {
   valeur = 9;
 }  
 }
 }
 
 break;

 case btnUP:
 {
 if (up < 6)
 {
 up++;
 }
 else 
 {
 up=0; 
 }
 }
 
 break;

 case btnDOWN:
 {
 if (up > 0) 
 {
 up--;
 }
 else
 { }
 }
 
 break;

 case btnSELECT:
 {
 delay(100); // delay to debounce switch
 choix = !choix;
 }
 break;

 case btnNONE:
 { }
 
 break;
 
 }
 ancien_boutton = lcd_key;
 }
 if (strcmp(menu_text[up][droit], "null") == 0) // le test pour savoir si il y a un sous menu
 {
 droit = 0;
 } 
 else { }
}

/*******************************************************
*******************************************************/

// Fonction qui gère l'affichage du menu 

void Affichagemenutext()
{
 lcd.setCursor(0,0); lcd.print("               ");
 lcd.setCursor(0,0); lcd.print(menu_text[up][droit]);
 delay(10); 
}


/*******************************************************
*******************************************************/

// Fonction qui gère l'effacement de la seconde ligne

void Effaceligne2 ()
{
 lcd.setCursor(0,1);
 lcd.print("                ");
}

/*******************************************************
*******************************************************/

// Fonction qui gère le menu valeur
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

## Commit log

2014-04-13 First commit Somme files are added, schématics, pictures, kicad's source files
    [Fourcheoptique.sch, Moteur_pap.kicad_pcb, Moteur_pap.sch]
2014-04-13 Schema with the Leonardo board added
2014-04-14 Add a picture of the display and the buttons
2014-04-27 Little bug corrected in counter display with negative value
    [Compteur_decompteur_motpap_55SI.ino]
2014-04-29 Display modified and managing a first point for easy reset
    [Compteur_decompteur_motpap_55SI_.ino]
2014-05-01 New picture of the guidewire & Fixed a display bug when resetting counter
    [Compteur_decompteur_motpap_55SI.ino]
2014-05-02 Picture of the steppermotror added
2014-05-02 add picture's electronic board
2014-05-05 Add 2 new pictures of the wire reel
2014-05-07 Add new picture of the guidewire & the brake system
